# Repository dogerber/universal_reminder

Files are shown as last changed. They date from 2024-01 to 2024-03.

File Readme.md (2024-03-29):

splash

# Universal reminder

Did I already take these pills today? Did I water the plants already? This device helps you track repetitive tasks. Set the times of day something needs doing and the message that should be displayed. When the task is done, shake the device to make the screen display, that it is done. The device will reset when the next task is due.

The device uses a eInk display and enters deep sleep in between tasks, to save as much energy as possible.

## Used parts

- [Adafruit Feather M0 Basic Proto](https://www.adafruit.com/product/2772)
- [Adafruit 2.9" Grayscale eInk](https://www.adafruit.com/product/4777)
- [Adafruit PCF8523 Real Time Clock](https://www.adafruit.com/product/3295)
- Tilt Sensor ([for example this](https://naltronic.de/zubehoer/elek.-bauteile/sonstige/651/1x-sw-200d-vibration-erschuetterung-neigung-sensor-kugel-tilt-schalter-sw200d))
- 1x Resistor (1 kOhm or similar)
- Battery (CR1220)
- LiPo Battery (I use a swatronic 1100 mAh from [here](https://www.swaytronic.ch/SWAYTRONIC-LiPo-1S-3.7V-1100mAh-35C-70C-JST))
- 3D printed enclosure (available in this repo or [here on Onshape](https://cad.onshape.com/documents/8f49303399ef22a7e39bc2af/w/fa5502a23fe9f76c9c39dbc8/e/11aa9429d28955ad08e092fa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))

<details> 
  <summary>Wiring diagram (click to open)</summary>
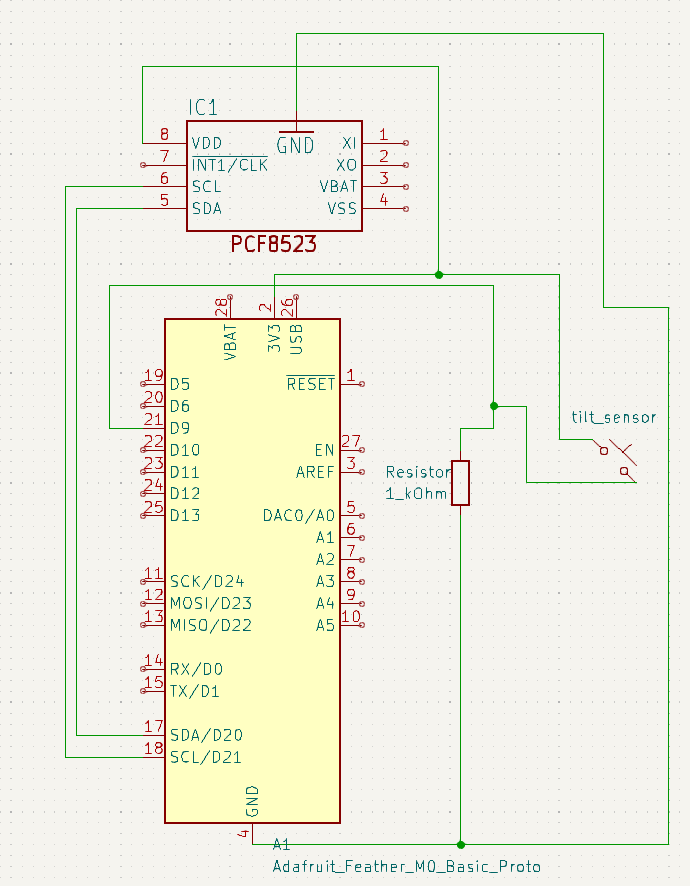
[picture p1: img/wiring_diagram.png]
   
</details>

## How to build

- Connect wires as shown [here](img/wiring_diagram.png)
- 3D print enclosure from [/3D_print](/3D_print)
- make sure that the tilt sensor is pointing downwards in the enclosure (wires upwards)
- Install these libraries:
  - [RTClib](https://github.com/adafruit/RTClib)
  - [Adafruit EPD](https://github.com/adafruit/Adafruit_EPD)
  - [Adafruit GFX and Adafruit GFX library](https://github.com/adafruit/Adafruit-GFX-Library)
  - [Arduino Low Power](https://github.com/arduino-libraries/ArduinoLowPower)
- Set time on RTC with this script [`set_RTC.ino`](code/set_RTC/set_RTC.ino)
- adjust the messages (`str_*`) and `times[]` for the tasks in [`universal_reminder.ino`](code/universal_reminder/universal_reminder.ino). Times are set as HHMM, so for example 13:45 becomes 1345 in the code.
- upload [`universal_reminder.ino`](code/universal_reminder/universal_reminder.ino)

## Troubleshooting

If the device every becomes unrepsonsive (can not upload code and power LED does not switch on), double-click the reset button and upload the basic "Blink" example. This always happens when the device enters deep sleep, so for trouble shooting replace deep sleep with a simple delay().

## Known issues

- The screen becomes grainy after some time. I don't know what is causing this.
- sometimes shaking the device resets the counter to 1 instead of 0.

## Resources

- [Arduino Guide to low power design](https://docs.arduino.cc/learn/electronics/low-power)
- [Good resource on interrupts by Nick Gammon](http://gammon.com.au/interrupts)

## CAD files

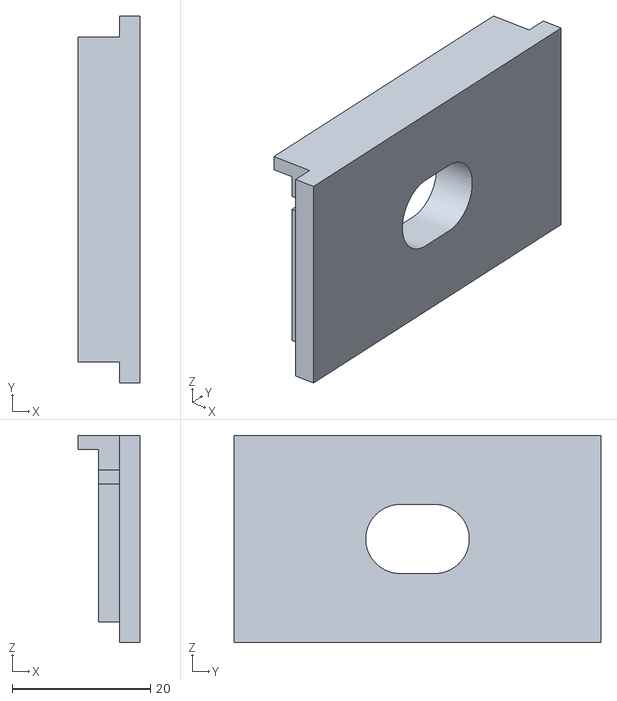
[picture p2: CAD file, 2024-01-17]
3D_print/SwissClockLid_V1_with_hole.stl
9.00 x 53.1 x 30.0

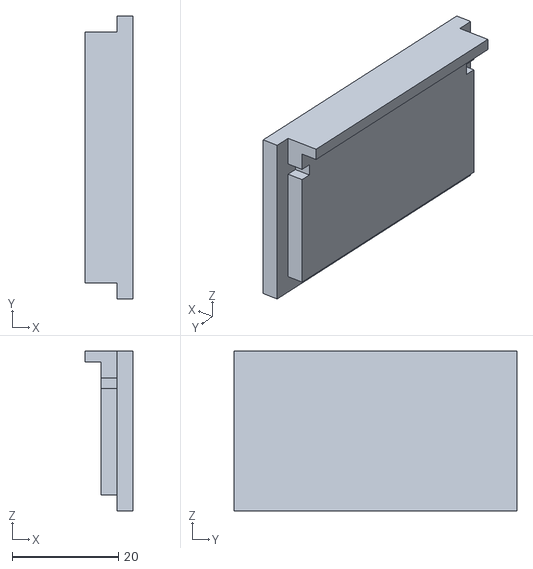
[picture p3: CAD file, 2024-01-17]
3D_print/SC - SwissClockLid_V1.stl
9.00 x 53.1 x 30.0

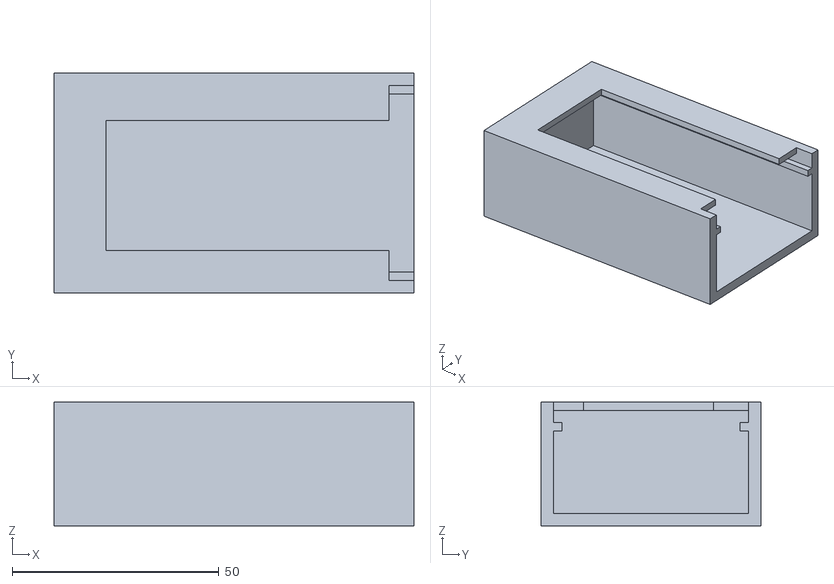
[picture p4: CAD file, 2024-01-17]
3D_print/SC - SwissClockBody_V1.stl
87.1 x 53.1 x 30.0

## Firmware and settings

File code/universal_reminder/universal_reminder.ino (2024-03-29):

/*
  Universal Reminder by Dominic Gerber
  see also: https://github.com/dogerber/universal_reminder

  Displays the current date and if a task has already been done or not. Tasks are triggered by times of the day.
  In between the device goes to sleep to save energy. 
*/

#include "ArduinoLowPower.h"    // for deep sleep, see https://www.arduino.cc/reference/en/libraries/arduino-low-power/
#include "Adafruit_ThinkInk.h"  // for the eInk screen
#include <Wire.h>
#include <RTClib.h>  // for RTC


// Definitions for Display
#define EPD_DC 10     // can be any pin, but required!
#define EPD_CS 9      // can be any pin, but required!
#define EPD_BUSY -1   // can set to -1 to not use a pin (will wait a fixed delay)
#define SRAM_CS 6     // can set to -1 to not use a pin (uses a lot of RAM!)
#define EPD_RESET -1  // can set to -1 and share with chip Reset (can't deep sleep)
#define COLOR1 EPD_BLACK
#define COLOR2 EPD_LIGHT
#define COLOR3 EPD_DARK
#define FONT_NAME FreeSans9pt7b
#define FONT_NAME2 FreeSansBold9pt7b
#include <Fonts/FreeSans9pt7b.h>
#include <Fonts/FreeSansBold9pt7b.h>

ThinkInk_290_Grayscale4_T5 display(EPD_DC, EPD_RESET, EPD_CS, SRAM_CS, EPD_BUSY);

RTC_PCF8523 rtc;  // real time clock object


// Pin used to trigger a wakeup (tilt sensor)
const int PIN_TILT_SENSOR = 5;

// variables
volatile bool woke_through_interrupt = false;
volatile int tasks_to_do = 0;
volatile int tasks_to_do_before = -1;
int time_to_wait_min = 0;

int times[] = { 500,};  // times where doing needs to be done, Represented as HHMM, in ascending order


// swissgerman char daysOfTheWeek[7][12] = { "Sunntig", "Maentig", "Zistig", "Mittwuch", "Dunnstig", "Fritig", "Samstig" };
char daysOfTheWeek[7][12] = { "Sunday", "Monday", "Tuesday", "Wednesday", "Thursday", "Friday", "Saturday" };

// messages to display
char str_all_done[] = "[x] all tasks done";
char str_one_undone[] = "[ ] one task undone";
char str_multiple_undone[] = "[[  ]] multiple tasks undone";



void change_detected() {
  // called on interrupt through the tilt sensor
  if (!woke_through_interrupt && tasks_to_do !=0) {
    woke_through_interrupt = true;
    tasks_to_do = 0;
  }
}


// Function to find the closest time in the future from the given time, input in HHMM
int findClosestTime(int currentTime) {
  int closestTime = -1;  // return -1 for no times in the future
  int timeDifference = 2500;

  for (int i = 0; i < sizeof(times) / sizeof(times[0]); i++) {
    int tempDifference = times[i] - currentTime;
    if ((tempDifference < timeDifference) && (tempDifference > 0)) {
      closestTime = times[i];
      timeDifference = tempDifference;
    }
  }
  return closestTime;
}



void update_display() {
  // check if anything changed
  if (true) { //was: tasks_to_do != tasks_to_do_before
    woke_through_interrupt = true;  // prevents interruption (?)
    display.clearBuffer();          // clear screen

    // print date on display
    if (true) {
      DateTime now = rtc.now();
      display.setFont(&FONT_NAME);
      display.setCursor(50, 15);
      display.setTextSize(1);
      display.print(daysOfTheWeek[now.dayOfTheWeek()]);
      display.print(" - ");
      display.print(now.day());
      display.print(".");
      display.print(now.month());
      display.print(".");
      display.print(now.year());
      display.print(".");
      display.drawLine(0, 20, 300, 20, COLOR1);
    }

    // write how many tasks are to do
    display.setCursor(20, 68);
    display.setTextSize(1);

    if (tasks_to_do == 0) {
      display.setFont(&FONT_NAME);  // normal
      display.println(str_all_done);
    } else if (tasks_to_do == 1) {
      display.setFont(&FONT_NAME2);  // bold
      display.println(str_one_undone);
    } else {
      display.setFont(&FONT_NAME2);  // bold
      display.println(str_multiple_undone);
    }



    // add info for next wakeup
    if (true) {  //todo add tasks_to_do == 0 &&
      // determine next time
      DateTime now = rtc.now();
      DateTime next_task = now + TimeSpan(0, time_to_wait_min / 60, time_to_wait_min % 60, 0);

      // write to screen
      display.setCursor(30, 120);
      display.setFont(&FONT_NAME);
      display.print(" next task: ");
      if (now.day() != next_task.day()) {
        display.print("tomorrow, ");
      }
      display.print(next_task.hour());
      display.print(":");
      if (next_task.minute() < 10) { display.print("0"); }
      display.print(next_task.minute());

      // write when last updated
      if (false) {
        display.setCursor(30, 90);
        display.print("last done:");
        display.print(daysOfTheWeek[now.dayOfTheWeek()]);
        display.print(" - ");
        display.print(now.day());
        display.print(".");
        display.print(now.month());
        display.print(".");
        display.print(now.hour());
        display.print(":");
        display.print(now.minute());
      }

      // debug: output informations
      if (false) {
        display.setCursor(30, 90);
        display.setFont(&FONT_NAME);
        display.print("upd");
        display.print(now.hour());
        display.print(":");
        display.print(now.minute());
        display.print(", wait");
        display.print(time_to_wait_min);
        display.print(", ttd");
        display.print(tasks_to_do);
        display.print(", ttdb");
        display.print(tasks_to_do_before);
      }
    }




    // reset flags
    tasks_to_do_before = tasks_to_do;

    display.display();
  }

  // reset flag
  woke_through_interrupt = false;
}

void setup() {
  Serial.begin(115200);

  // set pin Modes
  pinMode(PIN_TILT_SENSOR, INPUT);
  // initialize digital pin LED_BUILTIN as an output.
  pinMode(LED_BUILTIN, OUTPUT);

  // Attach a wakeup interrupt for tilt sensor
  LowPower.attachInterruptWakeup(digitalPinToInterrupt(PIN_TILT_SENSOR), change_detected, CHANGE);

  // start screen
  display.begin(THINKINK_GRAYSCALE4);
  display.clearBuffer();
  display.setTextSize(1);
  display.setTextColor(EPD_BLACK, EPD_WHITE);
  display.setFont(&FONT_NAME);

  // setup RTC
  if (!rtc.begin()) {
    Serial.println("Couldn't find RTC");
    display.setCursor(10, 64);
    display.print("Could not find RTC, lost power or missing?");
    display.display();
    while (1)
      ;
  }

  // display welcome message
  display.setCursor(10, 64);
  display.print("Universal Reminder v1.0");
  display.setCursor(20, 84);
  display.display();
  delay(500);

  // Infos to Serial
  Serial.println("");
  Serial.println("Started with code universal_reminder_code.ino by Dominic Gerber");
  Serial.println("see online www.github.com/dogerber/universal_reminder");
  Serial.println("");
}



void loop() {
  digitalWrite(LED_BUILTIN, HIGH);
  if (!woke_through_interrupt) {
    tasks_to_do++;
    if (tasks_to_do > 2) { tasks_to_do = 2; }  // cap to prevent refreshes
  } else {
    // loop started through interrupt, do no tadd a task
<<<<<<< HEAD
    woke_through_interrupt = false;  // reset flag
=======
    woke_through_interrupt = false; // reset flag
>>>>>>> 0b7f7f53a27ccd6c19c0a016620ad6031855e2a6
  }

  // get time from rtc
  DateTime now = rtc.now();

  // Get the current time
  int currentHour = now.hour();
  int currentMinute = now.minute();
  int currentTime = currentHour * 100 + currentMinute;

  // Find the closest time in the future
  int closestTime = findClosestTime(currentTime);

  // handle case where no more reminders for today
  if (closestTime < 0) {
    closestTime = 2400 + times[0];
  }

  // calculate time to wait for next scheduled task
  time_to_wait_min = (closestTime / 100 - currentTime / 100) * 60 + (closestTime % 100 - currentTime % 100);

  // update screen
  update_display();

  //delay(6000);  //for debugging
  digitalWrite(LED_BUILTIN, LOW);
  LowPower.deepSleep(time_to_wait_min * 60 * 1000);
}

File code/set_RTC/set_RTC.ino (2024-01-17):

/*
Simple script to set the time. It takes the time from when the script is uploaded, so it will make a small mistake. 
*/

#include <Wire.h>
#include <RTClib.h>

RTC_PCF8523 rtc;

void setup() {
  Serial.begin(115200);

  if (!rtc.begin()) {
    Serial.println("Couldn't find RTC");
    while (1);
  }

  if (true) {
    Serial.println("Let's set the time!");
    rtc.adjust(DateTime(F(__DATE__), F(__TIME__)));
  }
}

void loop() {
  DateTime now = rtc.now();

  Serial.print(now.year(), DEC);
  Serial.print('/');
  Serial.print(now.month(), DEC);
  Serial.print('/');
  Serial.print(now.day(), DEC);
  Serial.print(" ");
  Serial.print(now.hour(), DEC);
  Serial.print(':');
  Serial.print(now.minute(), DEC);
  Serial.print(':');
  Serial.print(now.second(), DEC);
  Serial.println();

  delay(1000); // Wait for 1 second
}
